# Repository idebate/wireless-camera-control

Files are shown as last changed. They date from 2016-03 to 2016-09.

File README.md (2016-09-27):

wireless-camera-control
===========

Moteino based wireless control of (1) camera pan/tilt head and (2) zoom/focus/iris motor control via follow focus emulation.

Overview
--------

wireless-camera-control is a Moteino based standalone wireless controller for **multiple** pan/tilt heads based on the popular Bescor MP-101, along with provisions for controlling up to three geared motors for the implementation of zoom, follow focus and iris.

Requirements
------------

1. Moteino [USB preferred, but either would do] + RFM69 receiver ```http://www.lowpowerlab.com/```.
2. Bescor MP-101 pan/tilt head ```http://www.bescor.com/MP101.htm```.
3. EasyDriver stepper motor driver  ```http://www.schmalzhaus.com/EasyDriver/index.html```.
4. SparkFun Motor Driver TB6612FNG ```https://www.sparkfun.com/products/9457```.
5. NEMA 14/16 stepper motors ```http://www.omc-stepperonline.com/```.

Acknowledgements
----------------

1. Felix at LowPowerLab, for a great development platform.
2. B. Stott at the LowPowerLab forums, for the inspiration and the streamlined code examples.
3. Protechy, for the initial breakdown of the Bescor head, pinout diagrams and initial directions on PWM.

Future
------

Rough PTZ + Focus control completed - next in line is finer speed control, integration of limit stops for various lenses and integrated zoom/focus routines.

Licence
-------

wireless-camera-control is licensed under the GPL version 3+.

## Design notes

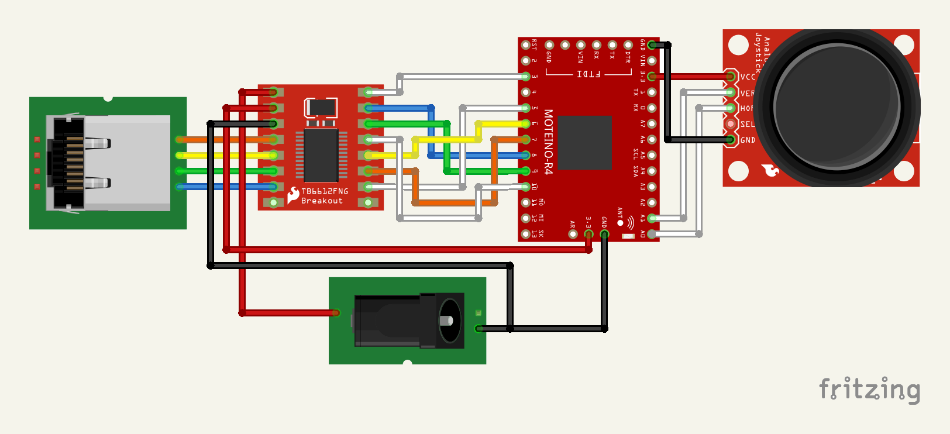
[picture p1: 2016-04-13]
Working/Wired/potentiometer-joystick-motor-driver/potentiometer-joystick-motor-driver.png

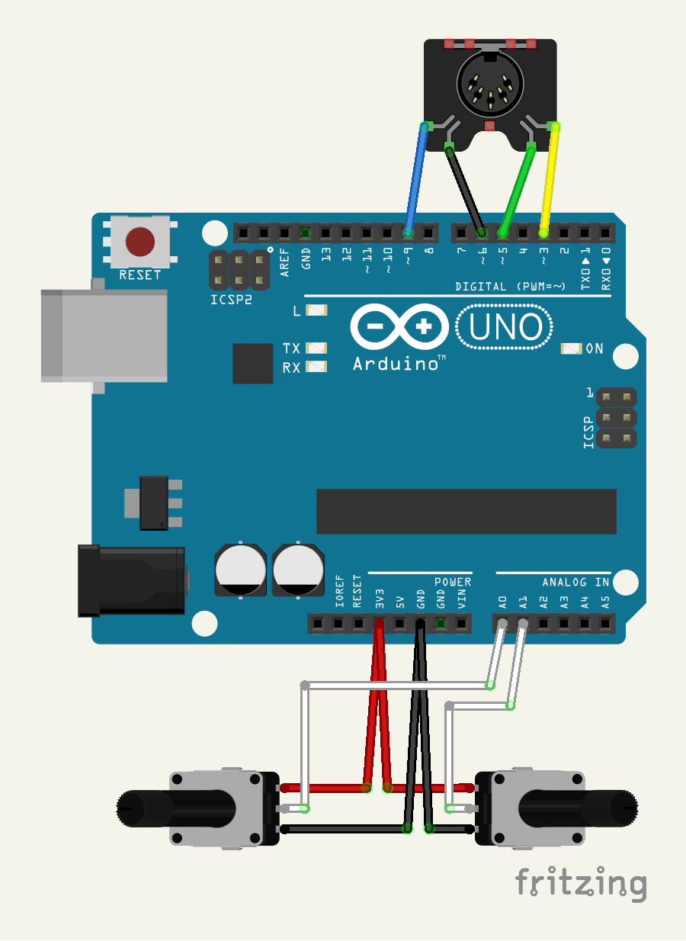
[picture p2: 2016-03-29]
Working/Wired/potentiometer-joystick/potentiometer-joystick-wired-control.png

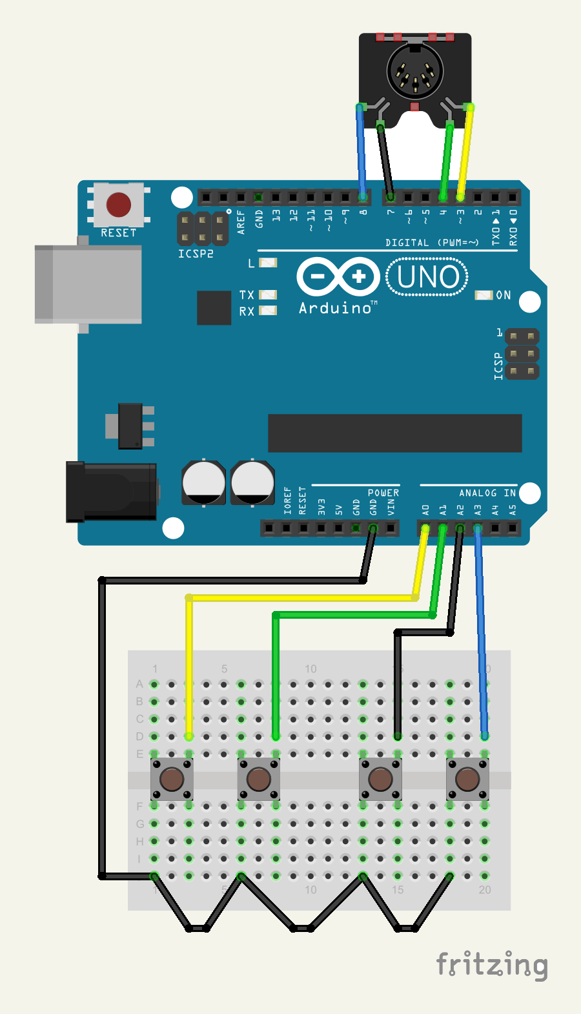
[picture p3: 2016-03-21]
Working/Wired/switch-joystick/switch-joystick-wired-control.png

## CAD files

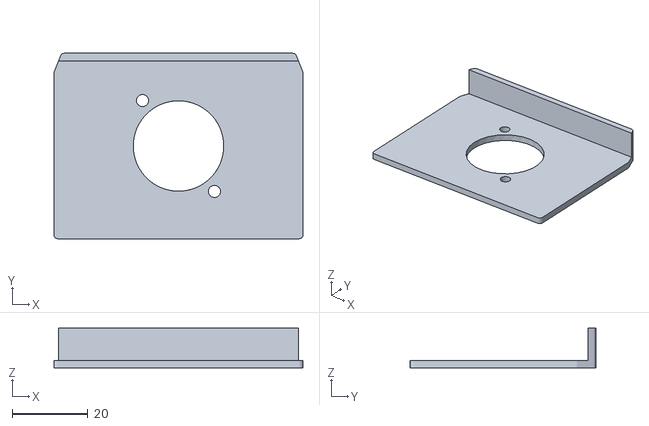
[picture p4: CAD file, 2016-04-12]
Resources/STL/bescor_back_plate.stl
65.7 x 49.0 x 10.5

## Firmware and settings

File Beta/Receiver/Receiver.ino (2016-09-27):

#include <RFM69.h>
#include <Wire.h>
#include <AccelStepper.h>

// Communication delays and serial configuration.
#define DELAY_STABILIZE 10
#define DELAY_COMMSTOP  1
#define COMM_COUNT      25
#define SERIAL_BAUD     9600
#define MOTOR_STEPS     50
#define MOTOR_SLP_TMR   2000

// Stepper motor configuration.
#define STP_ZOOM_MAXSPD 2000 
#define STP_ZOOM_MINSPD 0
#define STP_ZOOM_STEP   15
#define STP_ZOOM_DIR    14
#define STP_ZOOM_SLP    18
long timerZoom = 0;
AccelStepper stepperZoom(1, STP_ZOOM_STEP, STP_ZOOM_DIR);

// Stepper motor configuration.
#define STP_FOCUS_MINSPD 0 
#define STP_FOCUS_MAXSPD 2000 
#define STP_FOCUS_STEP   17
#define STP_FOCUS_DIR    16
#define STP_FOCUS_SLP    19
long timerFocus = 0;
AccelStepper stepperFocus(1, STP_FOCUS_STEP, STP_FOCUS_DIR);

// Motor driver settings.
#define MP_SPEED        3
#define MP_DIR1         8
#define MP_DIR2         9
#define MT_SPEED        5
#define MT_DIR1         7
#define MT_DIR2         6
#define MR_STBY        10

// Communication network settings.
#define DEFNODEID       1                         // ID of the receiver node. Unique to every receiver. Default value.
#define NETWORKID       100                       // ID of the network. Same across all nodes.
#define FREQUENCY       RF69_915MHZ
#define KEY             "wirelessCameraMV"        // Exactly 16 characters, needs to be exactly the same across all nodes.

RFM69 radio;                                      // Initialize radio.

// PTZPacket data structure.
typedef struct
{
  int   DirPan;
  int   DirTilt;
  int   DirZoom;
  int   DirFocus;
  int   SpeedPan;
  int   SpeedTilt;
  int   SpeedZoom;
  int   SpeedFocus;
  int   PositionFocus;
  int   PTZMovement;
} PTZPacket;

PTZPacket PTZData;

int commCount = 1;

int currentPos = 0;

int NodeID = 0;

// Node ID settings.
#define NODE_ID_1       4
#define NODE_ID_2       A6
#define NODE_ID_3       A7

void setup()
{
  // Set Node ID.
  getNodeID();    
  delay(DELAY_STABILIZE);

  // Set output pins.
  for (int i = 3; i <= 10; i++) {
    if (i != 4) {
      pinMode(i, OUTPUT);
    }
  }
  for (int i = 14; i <= 15 ; i++) {
    pinMode(i, OUTPUT);
  }

  pinMode(STP_ZOOM_SLP, OUTPUT);
  digitalWrite(STP_ZOOM_SLP, LOW);
  // Set zoom stepper.
  stepperZoom.setMaxSpeed(STP_ZOOM_MAXSPD);
  stepperZoom.setAcceleration(STP_ZOOM_MAXSPD / 2);
  stepperZoom.setSpeed(0);

  pinMode(STP_FOCUS_SLP, OUTPUT);
  digitalWrite(STP_FOCUS_SLP, LOW);
  // Set zoom stepper.
  stepperFocus.setMaxSpeed(STP_FOCUS_MAXSPD);
  stepperZoom.setAcceleration(STP_FOCUS_MAXSPD / 2);
  stepperFocus.setSpeed(0);

  // Initialize radio receiver.
  radio.initialize(FREQUENCY, NodeID, NETWORKID);
  radio.setHighPower();
  radio.encrypt(KEY);
  radio.promiscuous(false);

  delay(DELAY_STABILIZE);
}

void loop()
{
  for (int i = 1; i <= MOTOR_STEPS; i++) {
    stepperZoom.runSpeed();
    stepperFocus.runSpeed();
  }
  if (radio.receiveDone())
  {
    if (radio.DATALEN == sizeof(PTZPacket))
    {
      PTZData = *(PTZPacket*)radio.DATA;
      if (PTZData.DirPan != 0) {
        PTH_Move(1, PTZData.SpeedPan, PTZData.DirPan);
      }
      if (PTZData.DirTilt != 0) {
        PTH_Move(2, PTZData.SpeedTilt, PTZData.DirTilt);
      }

      // Only move the zoom motor if pan/tilt is not active. Working precaution, but can be eliminated.
      if (PTZData.DirPan == 0 && PTZData.DirTilt == 0) {
        if (PTZData.DirZoom != 0) { moveZoom(PTZData.DirZoom, PTZData.SpeedZoom); }
        if (PTZData.DirFocus != 0) { moveFocus(PTZData.DirFocus, PTZData.SpeedFocus, PTZData.PositionFocus); }
      }
      commCount = 0;
    }
  }
  else
  {
    if (CommDelayComplete())
    {
      PTH_Stop();
      stopZoom();
      stopFocus();
    }
  }
  delay(DELAY_COMMSTOP);
  checkZoomSleep();
  checkFocusSleep();
}

boolean CommDelayComplete()
{
  commCount += 1;
  if (commCount > (COMM_COUNT + 1)) {
    commCount = (COMM_COUNT + 1);
  }
  return (commCount == COMM_COUNT);
}

void PTH_Move(int motorNumber, int motorSpeed, int motorDirection)
{
  // motorNumber: 1 for Pan, and 2 for Tilt.
  // motorSpeed: Between a set minimum (typically 160 for lower voltage threshold of DC motors) and 255.
  // motorDirection: 1 for Left/Down, 2 for Right/Up.

  // Disable standby, stop Zoom and Focus steppers.
  digitalWrite(MR_STBY, HIGH);
  stopZoom();
  stopFocus();

  // Set direction pins.
  boolean inPin1 = LOW;
  boolean inPin2 = HIGH;
  if (motorDirection == 1) {
    inPin1 = HIGH;
    inPin2 = LOW;
  }

  if (motorNumber == 1)
  {
    if (PTZData.DirTilt == 0) {
      analogWrite(MT_SPEED, 0);
    }
    digitalWrite(MP_DIR1, inPin1); digitalWrite(MP_DIR2, inPin2); analogWrite(MP_SPEED, motorSpeed);
  }
  else
  {
    if (PTZData.DirPan == 0) {
      analogWrite(MP_SPEED, 0);
    }
    digitalWrite(MT_DIR1, inPin1); digitalWrite(MT_DIR2, inPin2); analogWrite(MT_SPEED, motorSpeed);
  }
}

void PTH_Stop()
{
  digitalWrite(MR_STBY, LOW);
  analogWrite(MP_SPEED, 0);
  analogWrite(MT_SPEED, 0);
}

void moveZoom(int dirZoom, int speedZoom)
{
  if (!digitalRead(STP_ZOOM_SLP)) {
    digitalWrite(STP_ZOOM_SLP, HIGH);
  }
  if (dirZoom == 2) {
    speedZoom = speedZoom * -1;
  }
  stepperZoom.setSpeed(map(speedZoom, 0, 100, STP_ZOOM_MINSPD, STP_ZOOM_MAXSPD));
  timerZoom = millis();
}

void stopZoom() {
  stepperZoom.setSpeed(0);
}

void checkZoomSleep() {
  unsigned long timerZoomX = millis();
  if (timerZoomX - timerZoom > MOTOR_SLP_TMR) {
    digitalWrite(STP_ZOOM_SLP, LOW);
  }
}

void moveFocus(int dirFocus, int speedFocus, int positionFocus)
{
  if (!digitalRead(STP_FOCUS_SLP)) {
    digitalWrite(STP_FOCUS_SLP, HIGH);
  }
  if (dirFocus == 2) {
    speedFocus = speedFocus * -1;
  }
  stepperFocus.setSpeed(map(speedFocus, 0, 100, STP_FOCUS_MINSPD, STP_FOCUS_MAXSPD));
  timerFocus = millis();
}

void stopFocus() {
  stepperFocus.setSpeed(0);
}

void checkFocusSleep() {
  unsigned long timerFocusX = millis();
  if (timerFocusX - timerFocus > MOTOR_SLP_TMR) {
    digitalWrite(STP_FOCUS_SLP, LOW);
  }
}

void getNodeID() {
  pinMode(NODE_ID_1, INPUT);
  pinMode(NODE_ID_2, INPUT);
  pinMode(NODE_ID_3, INPUT);
  if (digitalRead(NODE_ID_1) == 1) { NodeID += 1; } // Digital pin.
  if (analogRead(NODE_ID_2) > 900) { NodeID += 2; } // Analog pin.
  if (analogRead(NODE_ID_3) > 900) { NodeID += 4; } // Analog pin.
}

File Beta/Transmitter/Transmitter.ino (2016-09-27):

#include <RFM69.h>
#include <Wire.h>

#define POT_PAN         A5
#define POT_TILT        A6
#define POT_ZOOM        A7
#define LOWER_LIMIT     440
#define UPPER_LIMIT     590

#define ENC_A     10
#define ENC_B     11
#define ENC_PPR   800
#define ENC_TPR   40

volatile int lastEncoded = 0;
volatile long encoderValue = 0;
long lastencoderValue = 0;
long runningStopped = 0;
int lastMSB = 0;
int lastLSB = 0;

#define CAMERA_START    24                    // First pin in a bank of pins for camera selection buttons.
#define CAMERA_END      28                    // Last pin in a bank of pins for camera selection buttons.

#define NODEID          99
#define NETWORKID       100
#define GATEWAYID       1
#define FREQUENCY       RF69_915MHZ
#define KEY             "wirelessCameraMV"    //has to be same 16 characters/bytes on all nodes, not more not less!

RFM69 radio;                                  // Initialize radio.

#define SERIAL_BAUD     9600

typedef struct
{
  int   DirPan;                   // Integer value to hold the direction of pan. 0 = stop, 1 = left, 2 = right.
  int   DirTilt;                  // Integer value to hold the direction of tilt. 0 = stop, 1 = down, 2 = up.
  int   DirZoom;                  // Integer value to hold the direction of zoom. 0 = stop, 1 = down, 2 = up.
  int   DirFocus;                 // Integer value to hold the direction of focus. 0 = stop, 1 = down, 2 = up.
  int   SpeedPan;                 // Integer value to hold the speed of panning. Ranges from 0 to 255 to correspond with AnalogWrite(). Corrected to 160 to 255 to accomodate for voltage threshold.
  int   SpeedTilt;                // Integer value to hold the speed of tilting. Ranges from 0 to 255 to correspond with AnalogWrite(). Corrected to 160 to 255 to accomodate for voltage threshold.
  int   SpeedZoom;                // Integer value to hold the speed of zooming. Ranges from 0 to 100.
  int   SpeedFocus;               // Integer value to hold the speed of focusing.
  int   PositionFocus;            // Integer value to hold the position of the focus.
  int   PTZMovement;              // Integer value to represent a movement detection flag. 0 for no movement, 1 for any movement.
} PTZPacket;

PTZPacket PTZData;                // Initialize data packet to hold required values for node control.

int valPan = 0;
int valTilt = 0;
int valZoom = 0;
int cameraActive = 1;
int cameraLight[6] = {0, 18, 19, 20, 21, 22};

void setup()
{
  Serial.begin(SERIAL_BAUD);

  /* Setup encoder. */
  pinMode(ENC_A, INPUT);
  pinMode(ENC_B, INPUT);
  digitalWrite(ENC_A, HIGH); //turn pullup resistor on
  digitalWrite(ENC_B, HIGH); //turn pullup resistor on
  attachInterrupt(0, updateEncoder, CHANGE);
  attachInterrupt(1, updateEncoder, CHANGE);

  /* Initialize radio. */
  radio.initialize(FREQUENCY, NODEID, NETWORKID);
  radio.setHighPower();
  radio.encrypt(KEY);

  /* Initialize camera button lights. */
  for (int i = CAMERA_START; i <= CAMERA_END; i++) {
    pinMode(i, INPUT);
    digitalWrite(i, HIGH);
  }
  for (int i = 1; i <= 5; i++) {
    pinMode(cameraLight[i], OUTPUT);
    digitalWrite(cameraLight[i], LOW);
  }
  analogWrite(cameraLight[cameraActive], 255);
}

void handle_joystick()
{
  PTZData.DirPan = 0; PTZData.DirTilt = 0; PTZData.DirZoom = 0; PTZData.DirFocus = 0; PTZData.SpeedPan = 0; PTZData.SpeedTilt = 0; PTZData.SpeedZoom = 0; PTZData.SpeedFocus = 0; PTZData.PositionFocus = 0; PTZData.PTZMovement = 0;
  valPan = analogRead(POT_PAN);
  valTilt = analogRead(POT_TILT);
  valZoom = analogRead(POT_ZOOM);
  if (valPan < LOWER_LIMIT) {
    PTZData.DirPan = 1;
    PTZData.SpeedPan = map(valPan, 0, LOWER_LIMIT, 255, 160);
    PTZData.PTZMovement = 1;
  }
  if (valPan > UPPER_LIMIT) {
    PTZData.DirPan = 2;
    PTZData.SpeedPan = map(valPan, UPPER_LIMIT, 1023, 160, 255);
    PTZData.PTZMovement = 1;
  }
  if (valTilt < LOWER_LIMIT) {
    PTZData.DirTilt = 1;
    PTZData.SpeedTilt = map(valTilt, 0, LOWER_LIMIT, 255, 160);
    PTZData.PTZMovement = 1;
  }
  if (valTilt > UPPER_LIMIT) {
    PTZData.DirTilt = 2;
    PTZData.SpeedTilt = map(valTilt, UPPER_LIMIT, 1023, 160, 255);
    PTZData.PTZMovement = 1;
  }
  if (valZoom < LOWER_LIMIT) {
    PTZData.DirZoom = 1;
    PTZData.SpeedZoom = map(valZoom, 0, LOWER_LIMIT, 100, 1);
    PTZData.PTZMovement = 1;
  }
  if (valZoom > UPPER_LIMIT) {
    PTZData.DirZoom = 2;
    PTZData.SpeedZoom = map(valZoom, UPPER_LIMIT, 1023, 1, 100);
    PTZData.PTZMovement = 1;
  }
  handle_focus();
}

void handle_focus()
{
  int KeepPosition = lastencoderValue;
  if (lastencoderValue != encoderValue)
  {
    PTZData.PTZMovement = 1;
    if (encoderValue > lastencoderValue) {
      PTZData.DirFocus = 2;
    }
    else {
      PTZData.DirFocus = 1;
    }
    PTZData.PositionFocus = encoderValue;
    lastencoderValue = encoderValue;
    runningStopped = 0;
  }
  else
  {
    if (runningStopped == 0) {
      PTZData.DirFocus = 0;
      PTZData.PositionFocus = encoderValue;
      runningStopped = 1;
    }
  }
  if (runningStopped == 0) {
    PTZData.SpeedFocus = map(abs(PTZData.PositionFocus - KeepPosition), 0, 5, 0, 100);
  }
}

void handle_camera_selection()
{
  int cameraSelect = 0;
  for (int i = CAMERA_START; i <= CAMERA_END; i++) {
    if (!digitalRead(i)) {
      cameraSelect = i - CAMERA_START + 1;
    }
  }
  if ((cameraSelect != cameraActive) && (cameraSelect != 0))
  {
    cameraActive = cameraSelect;
    for (int i = 1; i <= 5; i++) {
      digitalWrite(cameraLight[i], LOW);
    }
    analogWrite(cameraLight[cameraActive], 255);
  }
}

void updateEncoder() {
  int MSB = digitalRead(ENC_A);
  int LSB = digitalRead(ENC_B);
  int encoded = (MSB << 1) | LSB;
  int sum  = (lastEncoded << 2) | encoded;
  if (sum == 0b1101 || sum == 0b0100 || sum == 0b0010 || sum == 0b1011) encoderValue ++;
  if (sum == 0b1110 || sum == 0b0111 || sum == 0b0001 || sum == 0b1000) encoderValue --;
  lastEncoded = encoded;
}

void loop()
{
  handle_joystick();
  handle_camera_selection();
  if (PTZData.PTZMovement != 0)
  {
    radio.send(cameraActive, (const void*)(&PTZData), sizeof(PTZData));   // transmit data to other end
  }
}

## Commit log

2016-02-11 Wired control sketch.
    Added initial working code for 8-wawired control of Bescor MP-101 via
    momentary switches.
2016-02-11 Revert "Wired control sketch."
    This reverts commit 5dfefcf9635e09265d9a51a8d8be1e4404412ecb.
    [wired-control.ino]
2016-02-11 Revert "Revert "Wired control sketch.""
    This reverts commit 68247d7d6604526caa3a095e922e9d3a35f69f90.
    [wired-control.ino]
2016-02-11 Remove wired control.
    Remove wired control. Stupid internet issues. :(
    [wired-control.ino]
2016-02-11 Added wired control.
    Wired control of Bescor MP-101 via four (4) momentary switches, allowing
    for simultaneous control in two directions, when desired.
2016-02-16 Proof of concept updated.
    Updated proof of concept with working wireless communication, for a
    switch based joystick.
2016-03-09 Added usage of potentiometer joystick.
    potentiometer based joystick. Uses pots to sense direction only, does
    not care for speed control. Yet.
    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
2016-03-17 Proof of concept updated.
    Updated wired control section for switch based joystick.
2016-03-21 Update proof of concept.
    Added mock schematic for the basic switch based joystick, courtesy of
    fritzing.
2016-03-29 Updated proof of concept.
    Added sketch and schematic for potentiometer based wired control.
2016-04-12 Added backplate STL.
    Added Resources folder with STL models for various 3D printed parts.
    [bescor_back_plate.stl]
2016-04-12 Added Breadboards to Resources.
    Added initial Fritzing breadboard layouts to facilitate code
    exploration.
    [wired_joystick_control.fzz, wired_switch_control.fzz]
2016-04-12 Added L293D Breadboard.
    Added sample breadboard featuring a joystick controller and an L293D
    motor driver.
    [wired_joystick_L293D.fzz]
2016-04-12 Updated L293D wiring.
    Updated L293D wiring.
    [wired_joystick_L293D.fzz]
2016-04-12 Added TB6612FNG Breadboard.
    Added TB6612FNG Breadboard.
    [wired_joystick_TB6612FNG.fzz]
2016-04-13 Revert "Updated folder structure."
    This reverts commit 38fc3b534de05e9ff529fe76e76165e8eb4126ac.
    [potentiometer-joystick-wired-control.ino, potentiometer-wireless-receiver.ino, potentiometer-wireless-transmitter.ino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]
2016-04-13 Revert "Updated folder structure."
    This reverts commit 4c71e8b9806fd12b934cb26675a567eb9ab16dcd.
    [potentiometer-joystick-wired-control.ino, potentiometer-wireless-receiver.ino, potentiometer-wireless-transmitter.ino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]
2016-04-13 Revert "Updated folder structure."
    This reverts commit 4c9847970fc143338aa3339a4a8d7a4b8aa55e7a.
    [potentiometer-joystick-wired-control.ino, potentiometer-wireless-receiver.ino, potentiometer-wireless-transmitter.ino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]
2016-04-13 Added TB6612FNG sketch.
    Added code for motor control via SparkFun TB6612FNG motor driver
    breakout.
2016-09-27 Completed beta driving code.
    Added pre-final working code for (1) pan and (2) tilt using the Bescor
    head, and (3) zoom and (4) focus using standalone stepper motors.
    Retained legacy code in "Working" folder.
2016-09-27 Added PCB.
    Added Gerber files for Receiver PCB v0.7.
    [Gerber_drill.DRL, Gerber_drill.GBL, Gerber_drill.GBO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]
